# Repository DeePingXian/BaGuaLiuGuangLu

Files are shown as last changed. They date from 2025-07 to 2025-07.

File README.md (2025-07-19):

# 八卦流光爐☆
這是個主要當彩燈使用的開源八卦爐專案DA☆ZE  
<table>
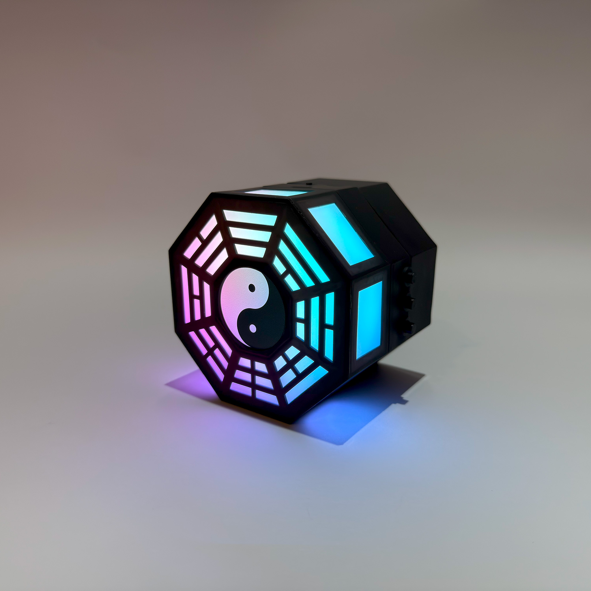
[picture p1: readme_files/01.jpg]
<tr><td align="center" colspan="2"><br></td></tr>
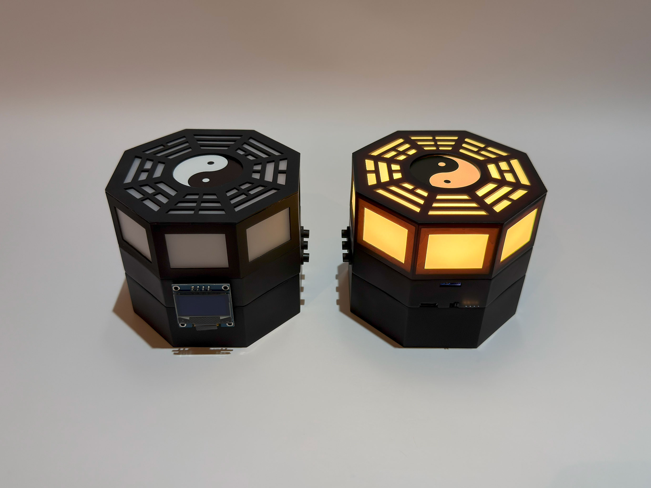
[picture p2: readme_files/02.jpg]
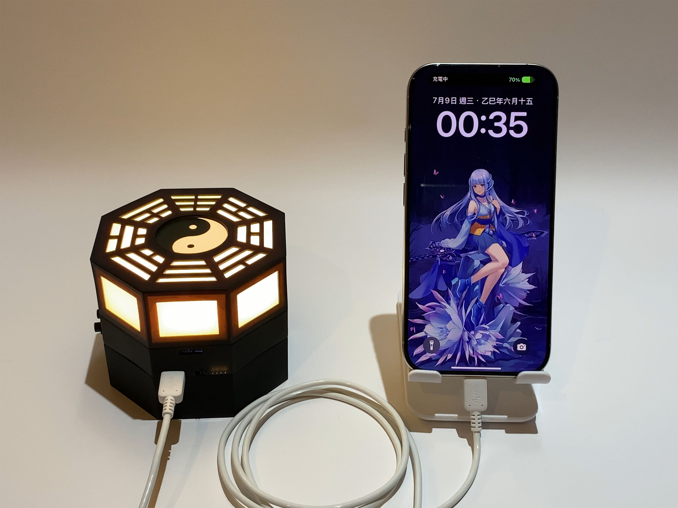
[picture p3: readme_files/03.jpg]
<tr><td align="center"><br></td><td align="center"><br></td></tr>
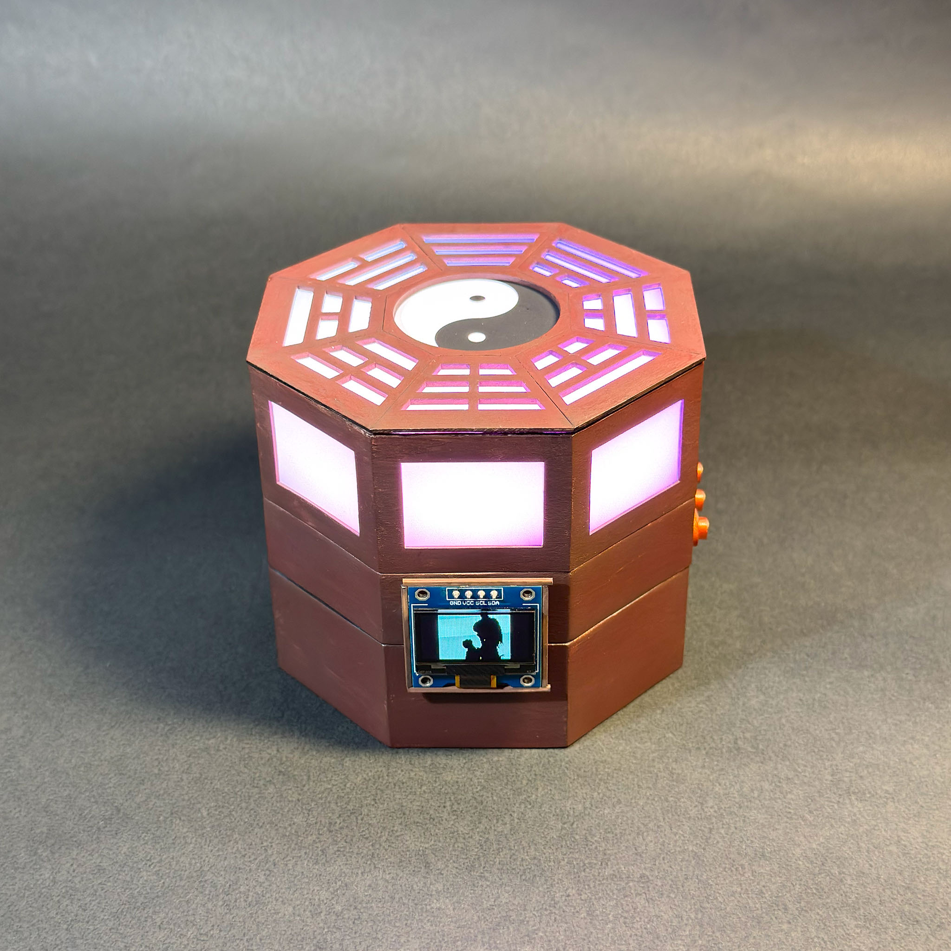
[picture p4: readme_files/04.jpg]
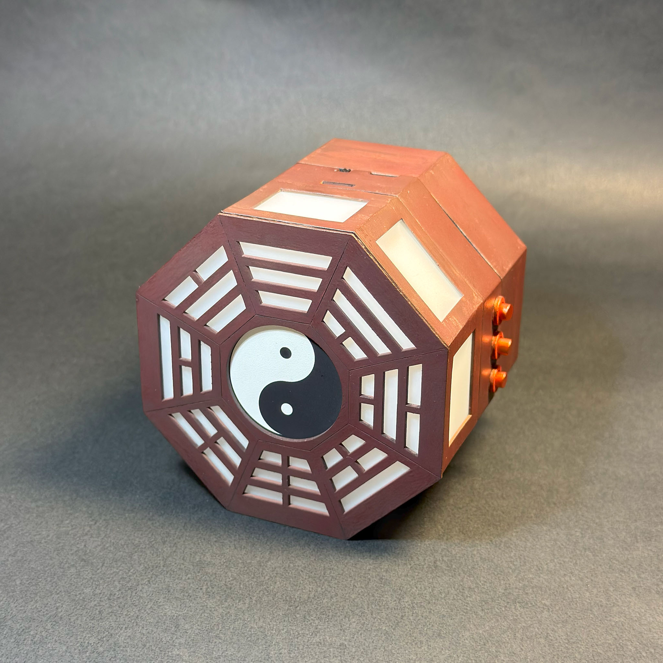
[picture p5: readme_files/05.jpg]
<tr><td align="center"><br></td><td align="center"><br></td></tr>
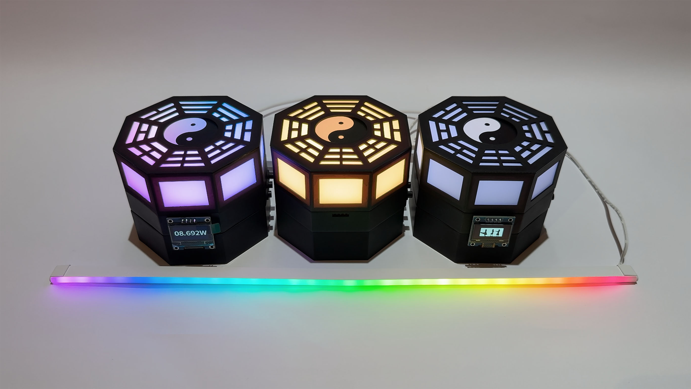
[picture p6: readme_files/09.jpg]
<tr><td align="center" colspan="2"><br></td></tr>
</table> 

## 功能介紹
- 自帶網頁+實體按鍵控制燈效
- 單USB-C孔之行動電源
- 顯示各項資訊的小螢幕
- 可外接電腦用之ARGB燈條
- 可選配藍牙喇叭模組
- OCP、OVP、OTP、ESD防護（未經任何標準檢驗）
- 有興趣也可自行修改成自己的版本
<br>

按鍵功能（按鍵面向自己時由左往右數）：  
- 按鍵1為燈控按鍵，短按一下調顏色、短按兩下調燈效模式、長按調燈光亮度
- 按鍵2為操控螢幕，短按切換畫面，長按開關螢幕
- 開機同時按住按鍵1、2一秒，可將整台裝置恢復預設值
- 按鍵3為行動電源按鍵，按一下開啟電源輸出，按兩下關閉輸出
<br>

螢幕顯示模式：  
- 充放電相關資訊、網路時鐘
- 充放電功率
- BadApple動畫
- 系統資訊

不安裝螢幕也可運作，請在關機狀態下插拔螢幕<br>
<br>
網頁控制功能，連線到此裝置的Wi-Fi後，在瀏覽器輸入小螢幕上的IP位址，即可進入控制頁面：<br>
預設SSID為「BaGuaLu」，密碼為「bagualu123」，IP為「192.168.4.1」<br>
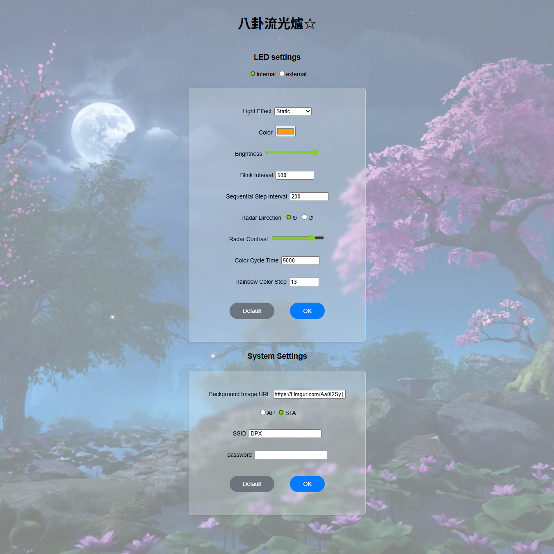
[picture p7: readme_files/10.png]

<br>
AP模式為裝置自成Wi-Fi基地台（預設值），STA則為連線至別的Wi-Fi<br>
設置完成後需要手動重新開機<br>
<br>
若設定連線到其他Wi-Fi，成功連上網際網路後，螢幕狀態顯示畫面最下面一欄會變為網路時鐘<br>
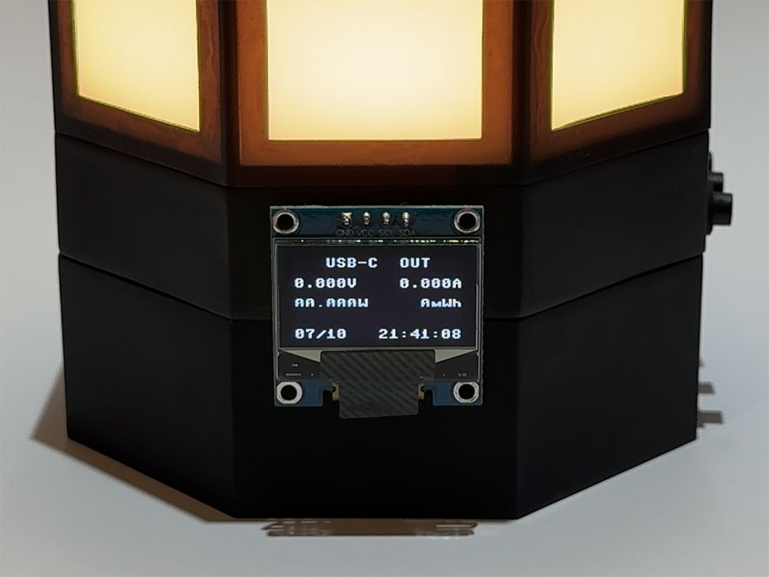
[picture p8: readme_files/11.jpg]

<br>
<br>

其餘事項
- 行動電源最高5V⎓3A輸出、2.4A輸入（實測2.6A），容量根據安裝的18650電池而定，若選擇製作教學中的型號，額定容量為6600mAh，實際容量會稍高一點
- 輸入電流大於4A時會啟動保護機制，無法充電，請排除狀況後重開機解除
- 當以接近最大功率充放電時，因過溫度保護機制設計的較敏感，會暫時降低功率，或直接關斷一段時間，直到溫度降低
- 裝置無法正常啟動、韌體更新完成時，請按照上方的方法重設裝置

## 展示短片
video (https://www.youtube.com/watch?v=Tj5yqzIPKYQ)

## 製作&組裝教學
本專案提供製作教學，若想瞭解技術細節，或實際上手製作，歡迎至<a href="https://github.com/DeePingXian/BaGuaLiuGuangLu/wiki">Wiki頁面</a>查看

## 製作人員
- 結構設計：<a href="https://thwiki.cc/%E6%B1%82%E9%97%BB%E5%B7%A5%E5%9D%8A">求聞工坊</a>
- 電路設計：<a href="https://www.facebook.com/DeePingXian">地平線 DeePingXian</a>
- 控制程式：<a href="https://www.facebook.com/DeePingXian">地平線 DeePingXian</a>
- 外殼模型：<a href="https://thwiki.cc/%E6%B1%82%E9%97%BB%E5%B7%A5%E5%9D%8A">求聞工坊</a>
- 外殼塗裝：<a href="https://www.facebook.com/j.kagamitsuki/posts/pfbid0qQWvzFg5CoFkT7tkbtXfqWopT1fieFPE1NWJFECgEJuv1Gb7SHNib1UmLF8mmVCvl">JKX鏡月</a>

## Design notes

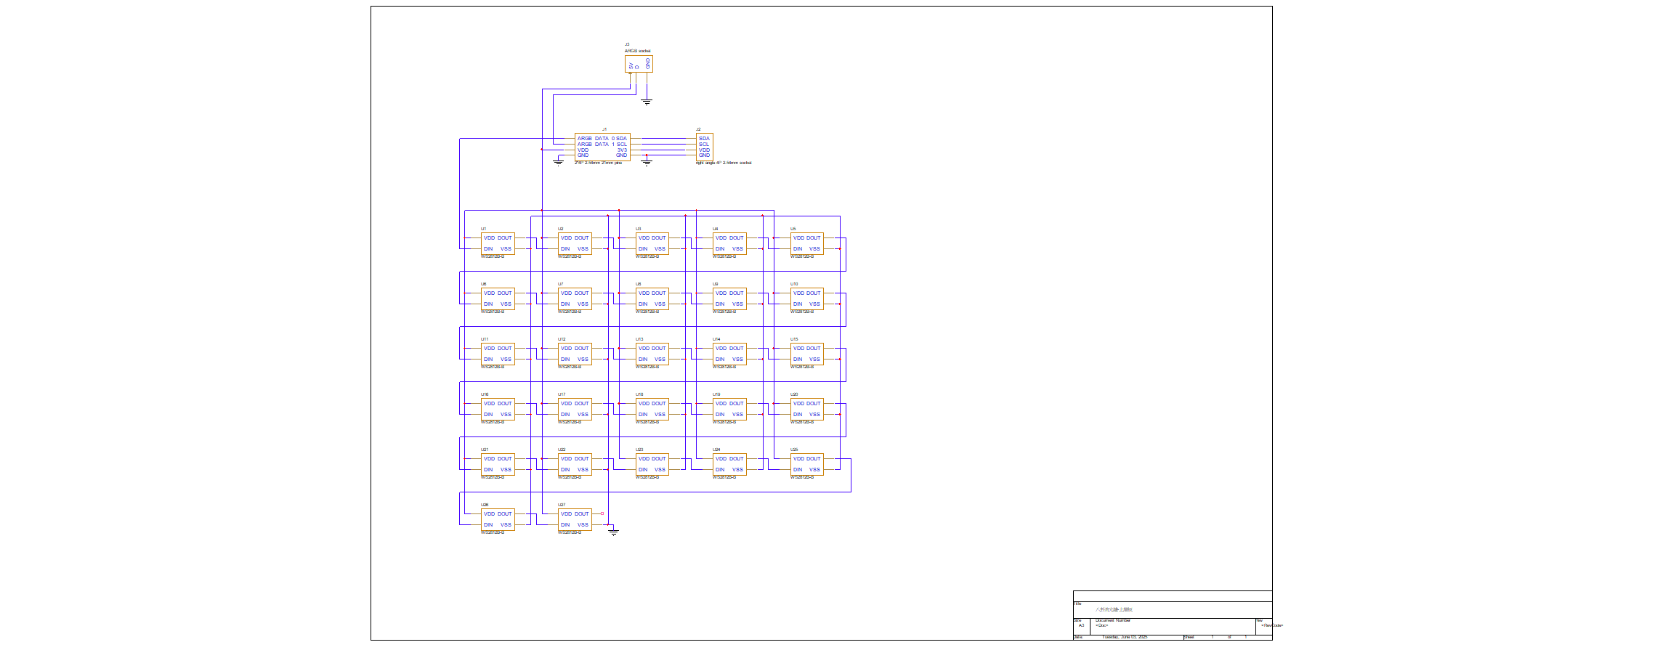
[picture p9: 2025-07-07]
circuit/upper_pcb/UPPER_PCB.png

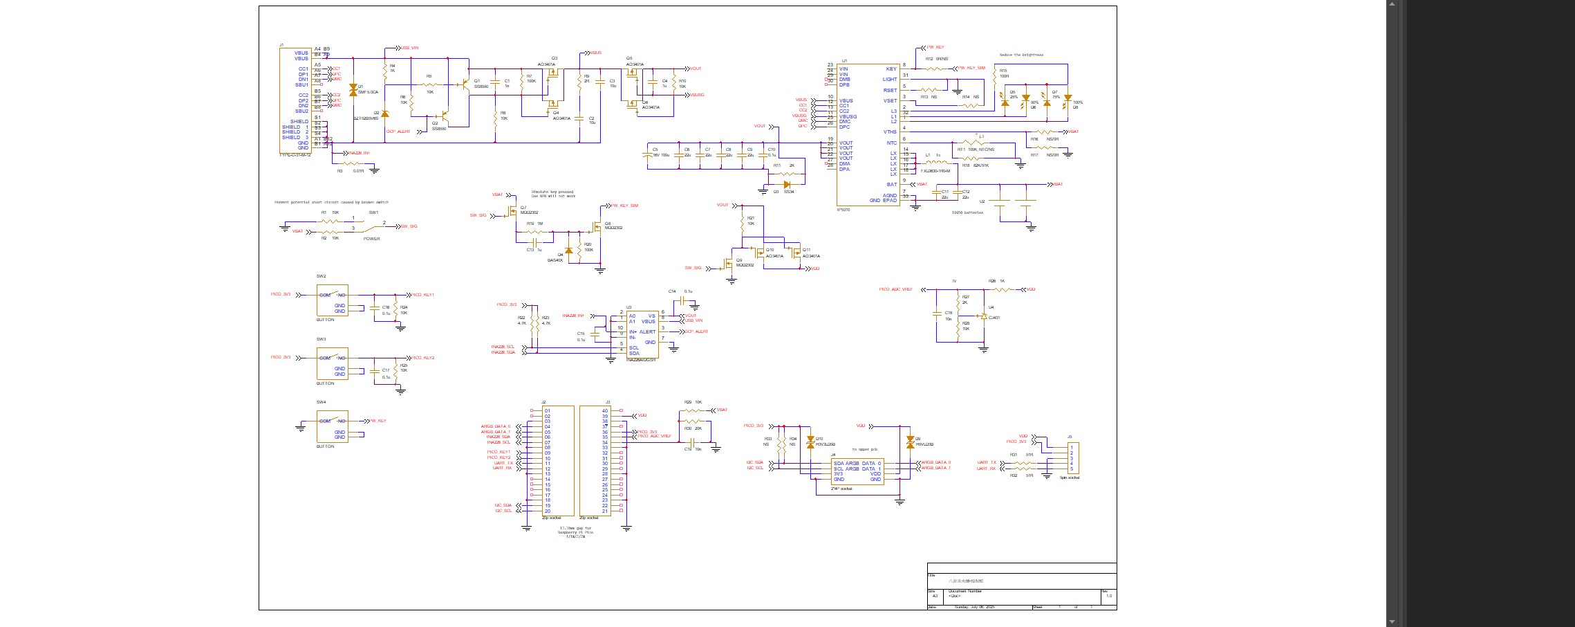
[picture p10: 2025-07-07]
circuit/control_pcb/CONTROL_CIRCUIT.png

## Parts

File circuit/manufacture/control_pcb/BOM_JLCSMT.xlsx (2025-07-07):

Comment | Designator | Footprint | JLCPCB Part #（optional）
10K R | R1,R2,R5,R6,R8,R10,R21,R24,R25,R28,R29 | 0603 | C25804
0.01 R | R3 | 1206 | C7467248
1K R | R4,R26 | 0603 | C21190
100K R | R7,R20 | 0603 | C25803
2 R | R9 | 0603 | C22977
2K R | R11,R27 | 0603 | C22975
0 R | R12 | 0603 | CC21189
100 R | R15 | 0603 | C22775
82K R | R18 | 0603 | C23254
4.7K R | R22,R23 | 0603 | C23162
1M R | R19 | 0603 | C22935
20K R | R30 | 0603 | C4184
51 R | R31,R32 | 0603 | C23197
100K_NTC | RT1 | 0603 | C919169
1n MLCC | C1 | 0603 | C1588
10u MLCC | C2,C3 | 0603 | C19702
1u MLCC | C4,C13 | 0603 | C15849
100u 16V Tantalum Capacitor | C5 | CASE-D-7343 | C129696
22u MLCC | C6,C7,C8,C9,C11,C12 | 0805 | C45783
0.1u MLCC | C10,C14,C15,C16,C17 | 0603 | C14663
10n MLCC | C18,C19 | 0603 | C57112
5V TVS | D1 | 1206 | C19077498
5.6V zener diode | D2 | SOD-323 | C19077435
schottky diode (SS34) | D3 | SMA | C8678
diode | D4 | SOD-523 | C22466370
LED | D5,D6,D7,D8 | 0603 | C2290
5V TVS | D9 | 0805 | C20615805
3.3V TVS | D10 | 0603 | C20615817
USB type-C connector | J1 | HRO_TYPE-C-31-M-12 | C165948
1*20P 2.54mm SMD socket | J2,J3 | SSM-120-L-SV-BE
2*4P 2.54mm socket | J4 | BCS-104-T-D-TE | C92271
1*5P 2.54mm socket | J5 | BCS-105-F-S-TE | C5116488
1uH inductor | L1 | INDM7066X300 | C167216
PNP_transistor | Q1,Q2 | SOT23-3 | C8542
N-MOSFET | Q7,Q8,Q9 | SOT23-3 | C427390
P-MOSFET | Q3,Q4,Q5,Q6,Q10,Q11 | SOT23-3 | C15127
right angle slide switch | SW1 | SW_EG1247 | C431547
right angle tactile switch | SW2,SW3,SW4 | SW_TS11-674-73-BK-160-RA-D | C2845271
IP5310 | U1 | QFN65P600X600X90-33N | C191176
18650 x2 battery case | U2 | 18650-PC4
INA226 | U3 | SOP50P490X110-10N | C49851
CJ431 | U4 | SOT23-3 | C3113

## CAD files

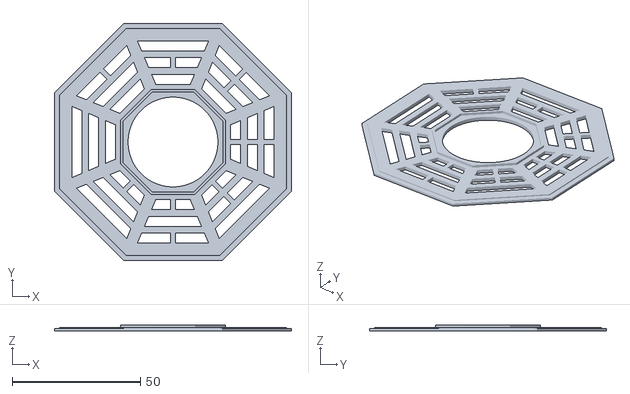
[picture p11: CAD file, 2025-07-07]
case/STL/top.stl
92.4 x 92.4 x 2.50

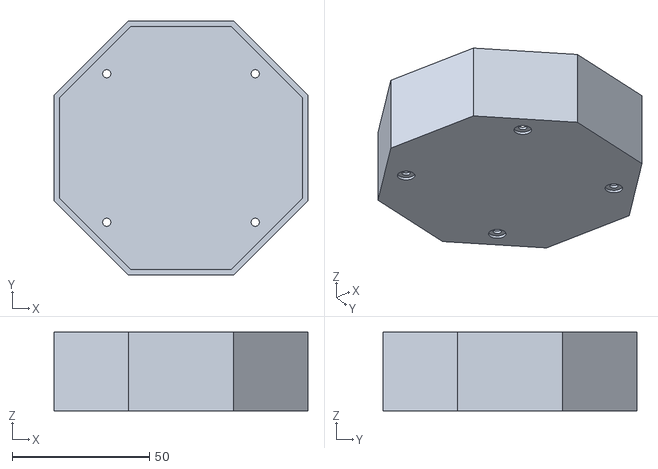
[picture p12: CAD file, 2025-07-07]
case/STL/lower.stl
92.4 x 92.4 x 28.6

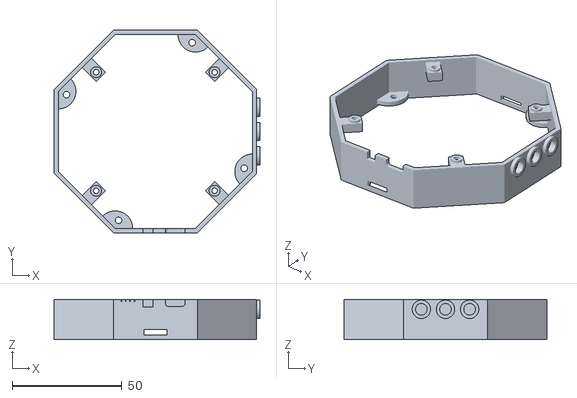
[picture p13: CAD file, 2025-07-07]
case/STL/mid.stl
93.9 x 92.4 x 18.3

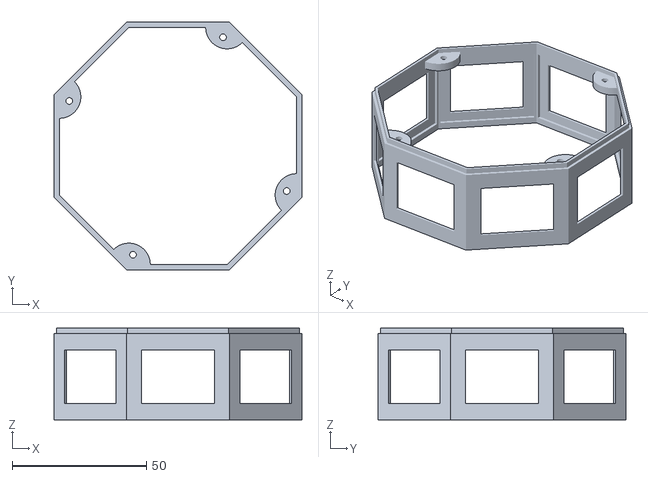
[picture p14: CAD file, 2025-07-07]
case/STL/upper.stl
92.4 x 92.4 x 34.1

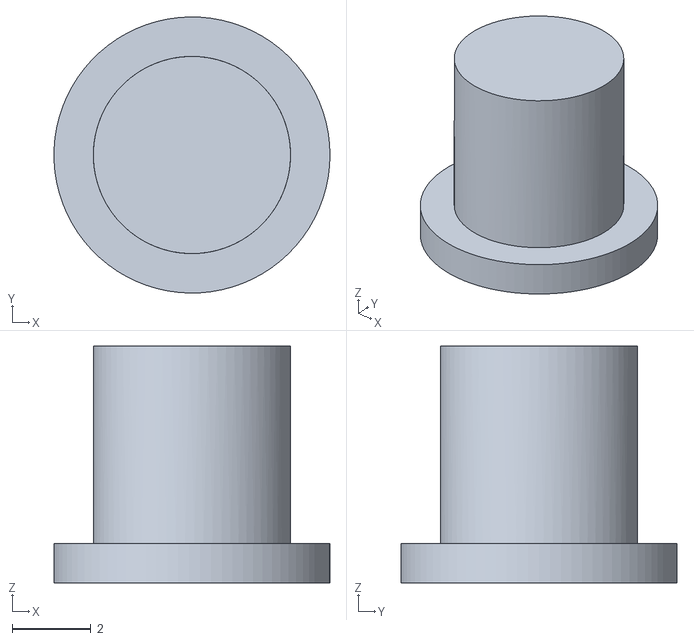
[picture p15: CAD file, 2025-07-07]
case/STL/btn.stl
7.00 x 7.00 x 6.00

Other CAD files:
case/LGP/顶面阴阳图均光板_面板打印_39x39x1mm.dwg

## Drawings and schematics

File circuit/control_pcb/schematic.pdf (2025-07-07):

Q1 SS8550 | C13 1u
L3 | 2 VSET | 3 VTHS | 4 RSET | 5 NTC | 6 AGND | 7

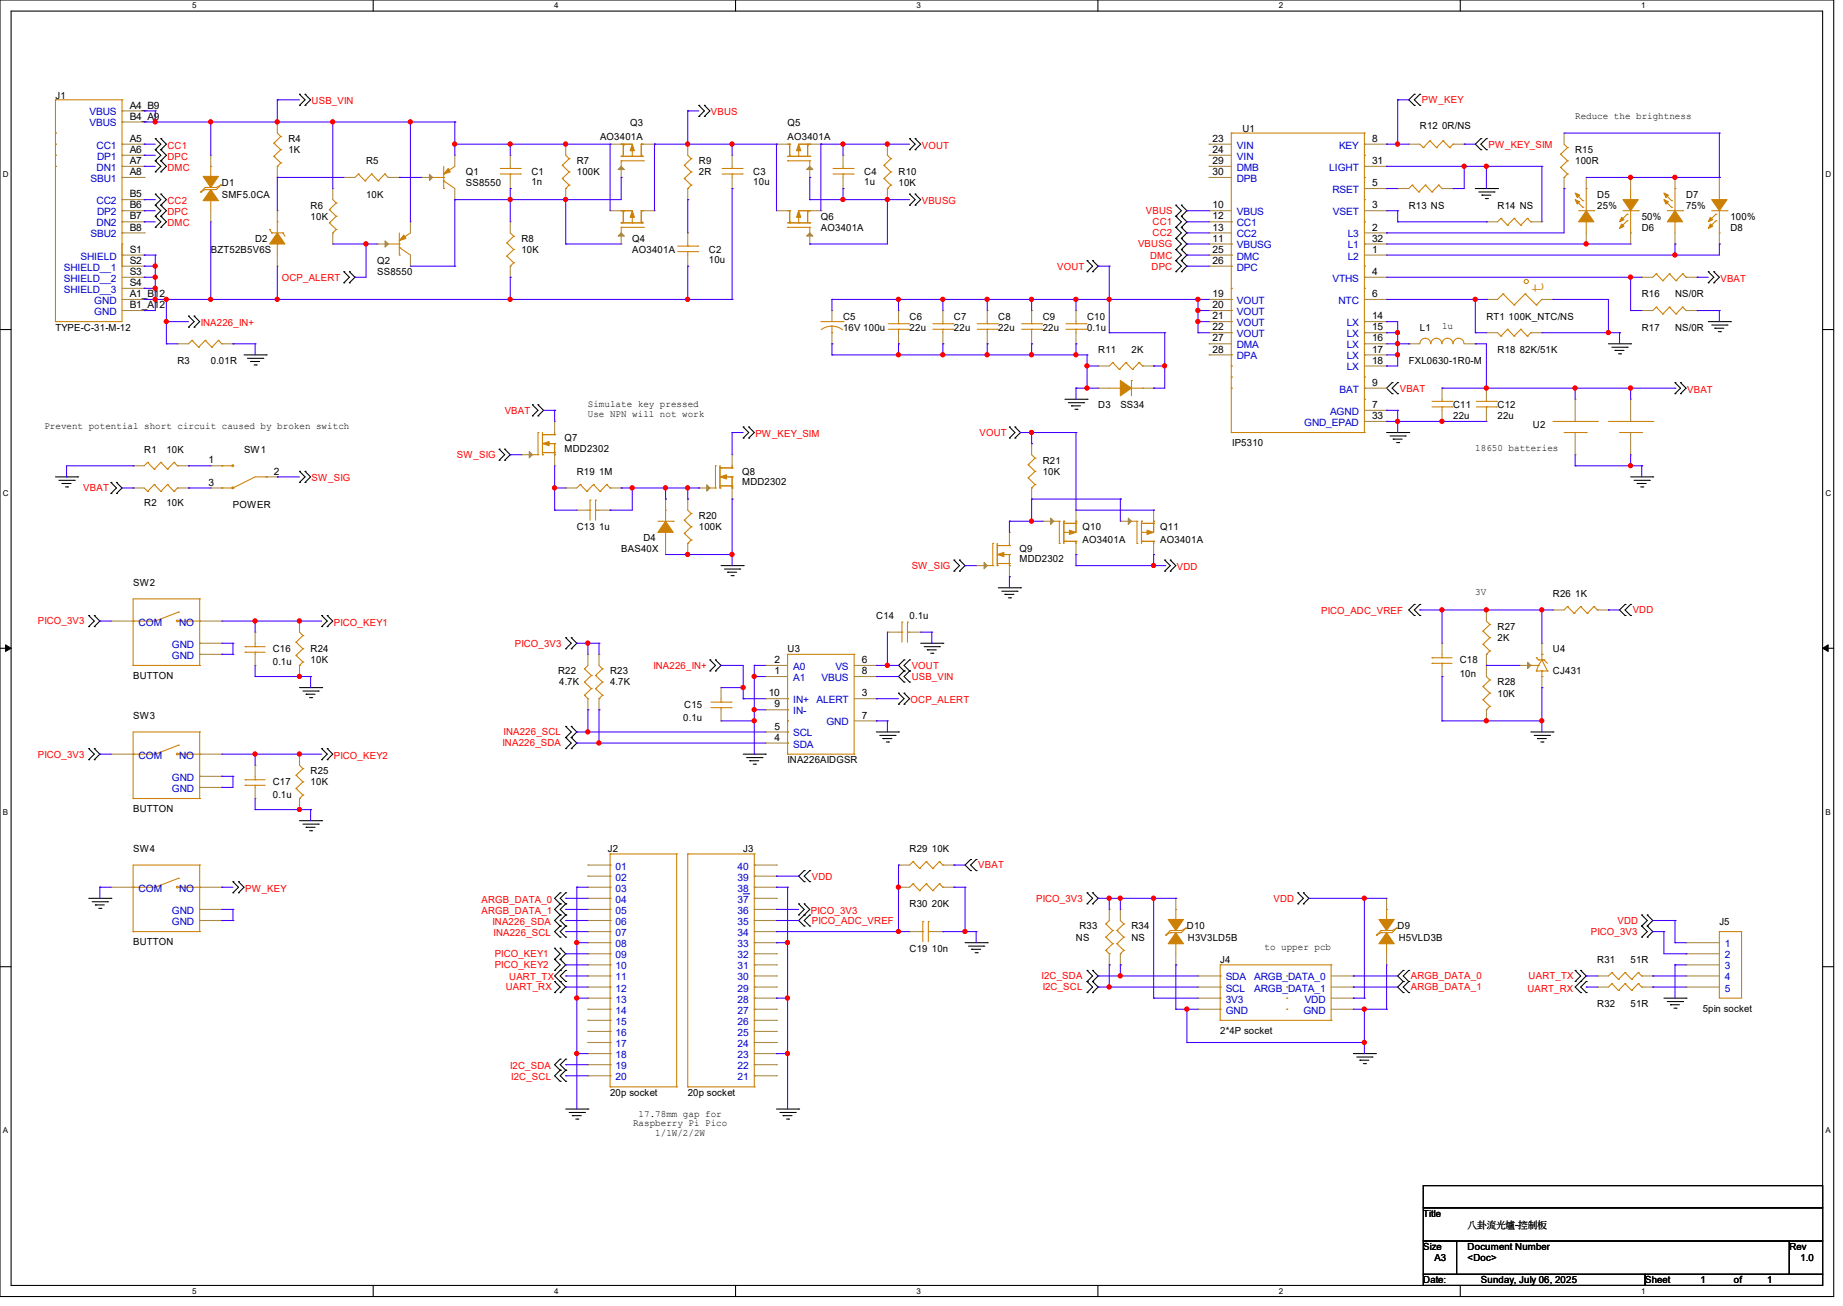
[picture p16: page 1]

Reduce the brightness VBUSG

Simulate key pressed
Use NPN will not work
Q7 MDD2302

Prevent potential short circuit caused by broken switch

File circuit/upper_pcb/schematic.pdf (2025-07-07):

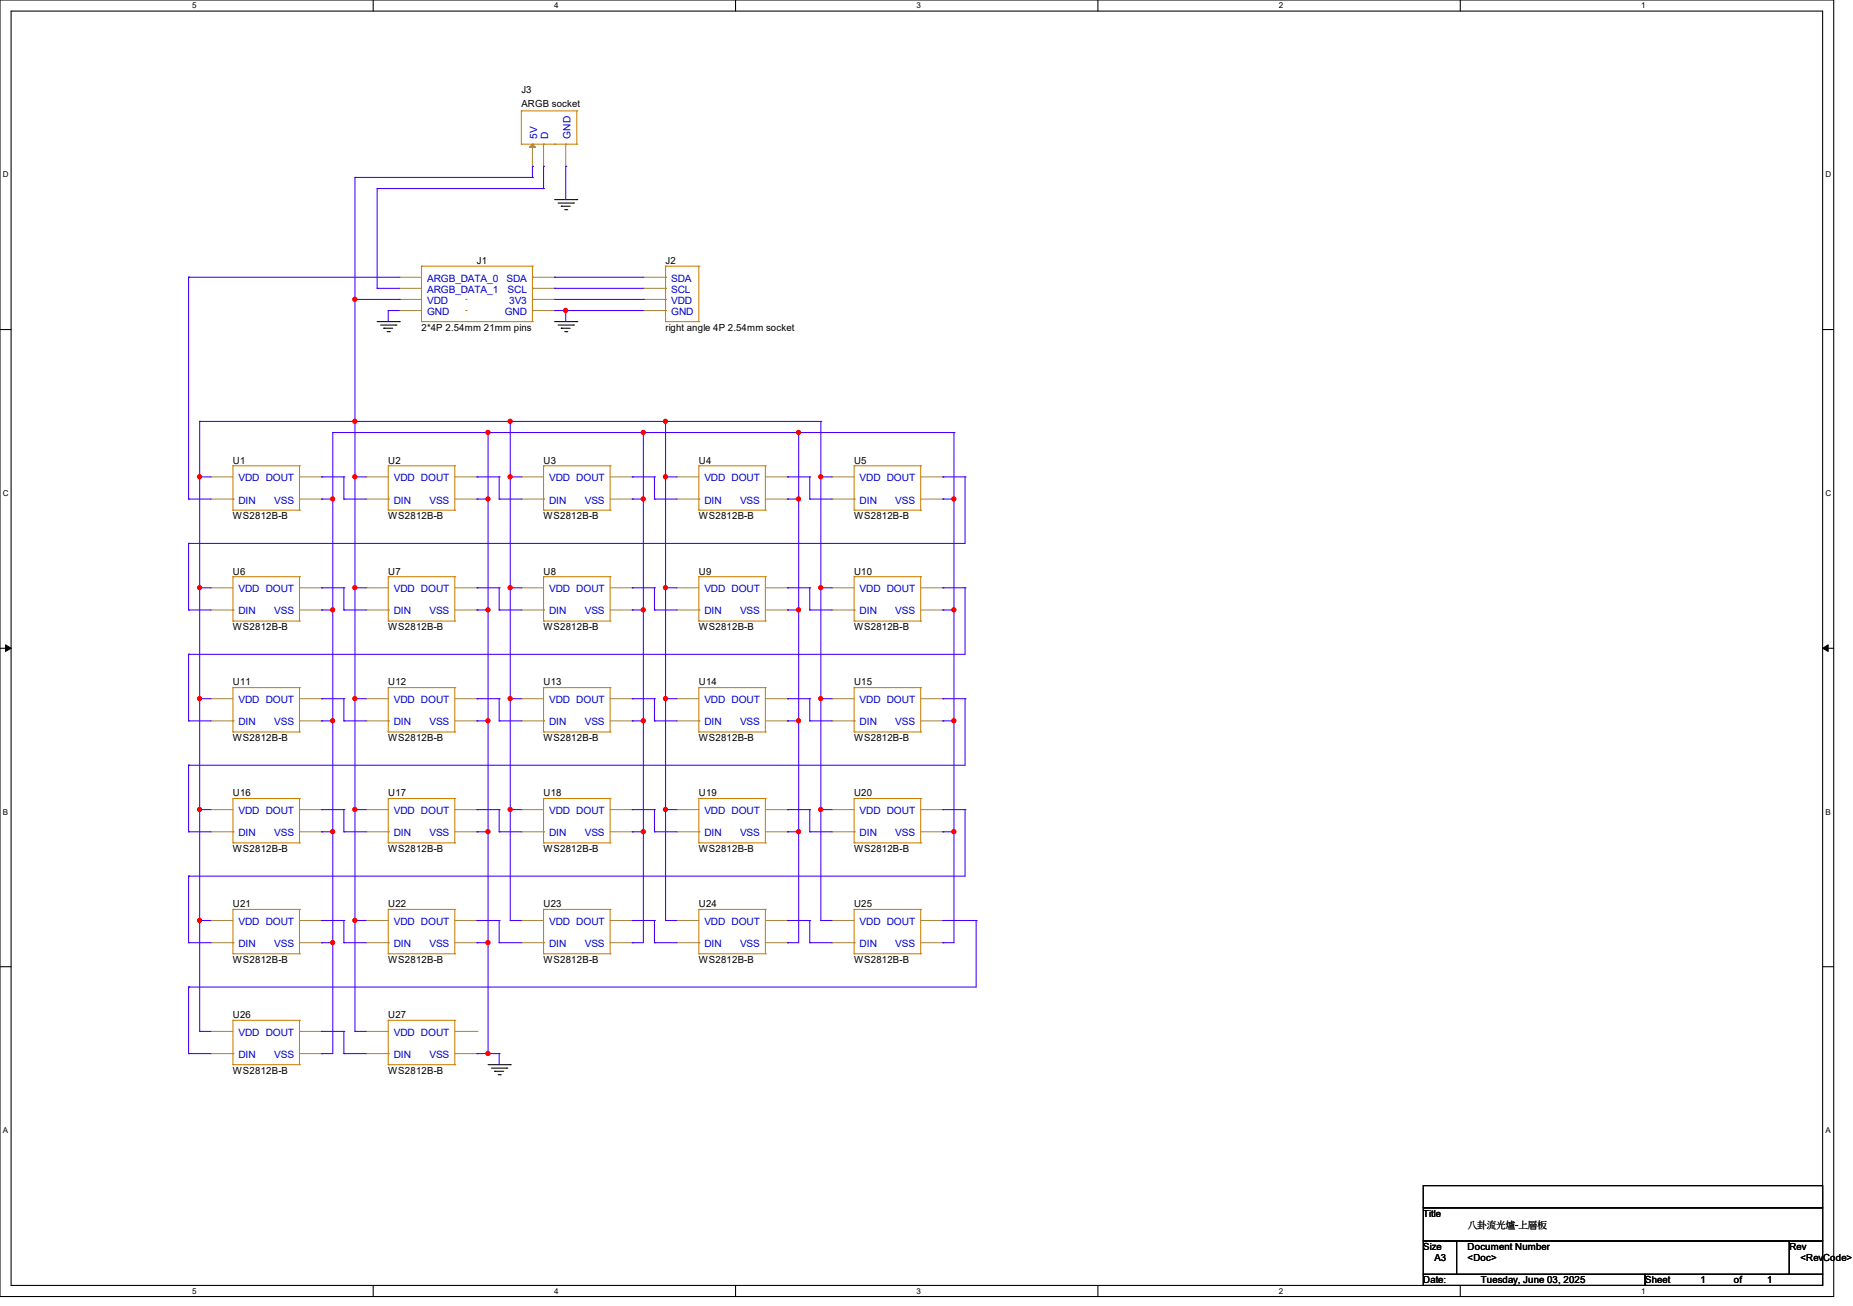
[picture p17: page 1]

right angle 4P 2.54mm socket SDA
SCL VDD GND

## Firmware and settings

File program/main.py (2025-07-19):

import machine, network, asyncio, gc, array, rp2, json, ubinascii, os, time, _thread, ina226, ssd1306, badapple, ntptime
from micropython import const

PROGRAM_VERSION = "25.07.07"
SUM_OF_INTERNAL_LEDS = const(27)
SHORT_PRESS_TIME = const(50)    #ms
LONG_PRESS_TIME = const(1000)
RELEASE_TIME = const(500)
SCREEN_REFRESH_INTERVAL = const(1000)
INA226_POSITIVE_CURRENT_COEFFICIENT = 0.999       #調整INA226誤差
INA226_NEGATIVE_CURRENT_COEFFICIENT = 0.9927
LOAD_INA226_INTERVAL = const(500)
ENABLE_INA226_OCP = const(1)
PICO_ADC_SINK_CURRENT = const(38)       #uA
NTP_SYNC_INTERVAL_HR = const(24)

ledButton = machine.Pin((6), machine.Pin.IN)
screenButton = machine.Pin((7), machine.Pin.IN)

settings = {}

def restore_default_settings(type=0):
    if type == 0:
        settings["wifi"] = {}
        settings["internalLed"] = {}
        settings["externalLed"] = {}
        settings["wifi"]["ssid"] = "BaGuaLu"
        settings["wifi"]["password"] = "bagualu123"
        settings["wifi"]["mode"] = 0
        settings["backgroundImageUrl"] = ""
        settings["internalLed"]["mode"] = 1     #0 關燈 1 單色開 2 單色閃 3 雷達 4 彩色循環 5 彩色流水
        settings["internalLed"]["color"] = [255, 160, 0]        #RGB format
        settings["internalLed"]["brightness"] = 100
        settings["internalLed"]["blinkInterval"] = 500
        settings["internalLed"]["sequentialStepInterval"] = 200
        settings["internalLed"]["sequentialDirection"] = True       #順時針亮起（否則逆時針）
        settings["internalLed"]["radarContrast"] = 80
        settings["internalLed"]["colorCycleTime"] = 5000
        settings["internalLed"]["rainbowColorStep"] = 13
        settings["externalLed"]["mode"] = 5     #0 關燈 1 單色開 2 單色閃 3 序列 4 彩色循環 5 彩色流水
        settings["externalLed"]["color"] = [255, 255, 255]
        settings["externalLed"]["brightness"] = 100
        settings["externalLed"]["blinkInterval"] = 500
        settings["externalLed"]["sequentialStepInterval"] = 200
        settings["externalLed"]["colorCycleTime"] = 5000
        settings["externalLed"]["rainbowColorStep"] = 10
        settings["externalLed"]["sumOfLeds"] = 30
    elif type == 1:
        settings["wifi"] = {}
        settings["internalLed"] = {}
        settings["externalLed"] = {}
        settings["wifi"]["ssid"] = "BaGuaLu"
        settings["wifi"]["password"] = "bagualu123"
        settings["wifi"]["mode"] = 0
        settings["backgroundImageUrl"] = ""
    elif type == 2:
        settings["internalLed"]["mode"] = 1
        settings["internalLed"]["color"] = [255, 160, 0]
        settings["internalLed"]["brightness"] = 100
        settings["internalLed"]["blinkInterval"] = 500
        settings["internalLed"]["sequentialStepInterval"] = 200
        settings["internalLed"]["sequentialDirection"] = True
        settings["internalLed"]["radarContrast"] = 80
        settings["internalLed"]["colorCycleTime"] = 5000
        settings["internalLed"]["rainbowColorStep"] = 13
    elif type == 3:
        settings["externalLed"]["mode"] = 5
        settings["externalLed"]["color"] = [255, 255, 255]
        settings["externalLed"]["brightness"] = 100
        settings["externalLed"]["blinkInterval"] = 500
        settings["externalLed"]["sequentialStepInterval"] = 200
        settings["externalLed"]["colorCycleTime"] = 5000
        settings["externalLed"]["rainbowColorStep"] = 10
        settings["externalLed"]["sumOfLeds"] = 30

    with open("./settings.json", "w", encoding="utf8") as f:
        json.dump(settings, f)

def load_settings():
    if not "settings.json" in os.listdir():
        restore_default_settings()
    global settings
    with open("./settings.json", "r", encoding="utf8") as f:
        settings = json.load(f)

def led_process():
    # https://github.com/raspberrypi/pico-micropython-examples/blob/master/pio/neopixel_ring/neopixel_ring.py
    # Raspberry Pi Pico 的PIO 程式，用於控制 WS2812B LED
    @rp2.asm_pio(sideset_init=rp2.PIO.OUT_LOW, out_shiftdir=rp2.PIO.SHIFT_LEFT, autopull=True, pull_thresh=24)
    def ws2812():
        T1 = 2
        T2 = 5
        T3 = 3
        wrap_target()
        label("bitloop")
        out(x, 1)               .side(0)    [T3 - 1]
        jmp(not_x, "do_zero")   .side(1)    [T1 - 1]
        jmp("bitloop")          .side(1)    [T2 - 1]
        label("do_zero")
        nop()                   .side(0)    [T2 - 1]
        wrap()

    class NeoPixel:
        def __init__(self, pin, ledSum, pioId, bpp=3, timing=1):
            self.ledSum = ledSum
            self.bpp = bpp
            self.pin = pin
            self.buf = array.array("I", [0] * ledSum)
            self.sm = rp2.StateMachine(pioId, ws2812, freq=8000000, sideset_base=pin)
            self.sm.active(1)

        def __len__(self):
            return self.ledSum

        def __getitem__(self, index):
            return ((self.buf[index]>>16)&0xFF, (self.buf[index]>>8)&0xFF, self.buf[index]&0xFF)

        def __setitem__(self, index, val):
            self.buf[index] = val[0]<<16 | val[1]<<8 | val[2]

        def write(self):
            # 將 RGB 資料轉換為 GRB，符合 WS2812B 的資料格式
            grb = array.array("I", [0] * self.ledSum)
            for i in range(self.ledSum):
                r = (self.buf[i]>>16) & 0xFF
                g = (self.buf[i]>>8) & 0xFF
                b = self.buf[i] & 0xFF
                grb[i] = (g<<16) | (r<<8) | b
            self.sm.put(grb, 8)

    def RGBtoHSV(colorInput):
        r = colorInput[0] / 255
        g = colorInput[1] / 255
        b = colorInput[2] / 255
        c_max = max(r, g, b)
        c_min = min(r, g, b)
        delta = c_max - c_min
        if delta == 0:
            h = 0
        elif c_max == r:
            h = (60 * ((g - b) / delta) + 360) % 360
        elif c_max == g:
            h = (60 * ((b - r) / delta) + 120) % 360
        else:
            h = (60 * ((r - g) / delta) + 240) % 360
        s = 0 if c_max == 0 else delta / c_max
        v = c_max
        return (int(round(h, 0)), int(round(s * 100, 0)), int(round(v*100, 0)))

    def HSVtoRGB(colorInput):
        #https://zh.m.wikipedia.org/zh-tw/HSL%E5%92%8CHSV%E8%89%B2%E5%BD%A9%E7%A9%BA%E9%97%B4
        color = [colorInput[0], colorInput[1], colorInput[2]]
        color[1] /= 100
        color[2] /= 100
        hi = color[0] // 60
        f = color[0] / 60 - hi
        p = color[2] * (1 - color[1])
        q = color[2] * (1 - f * color[1])
        t = color[2] * (1 - (1 - f) * color[1])
        if hi == 0:
            return (int(round(color[2] * 255, 0)), int(round(t * 255, 0)), int(round(p * 255, 0)))
        elif hi == 1:
            return (int(round(q * 255, 0)), int(round(color[2] * 255, 0)), int(round(p * 255, 0)))
        elif hi == 2:
            return (int(round(p * 255, 0)), int(round(color[2] * 255, 0)), int(round(t * 255, 0)))
        elif hi == 3:
            return (int(round(p * 255, 0)), int(round(q * 255, 0)), int(round(color[2] * 255, 0)))
        elif hi == 4:
            return (int(round(t * 255, 0)), int(round(p * 255, 0)), int(round(color[2] * 255, 0)))
        elif hi == 5:
            return (int(round(color[2] * 255, 0)), int(round(p * 255, 0)), int(round(q * 255, 0)))

    internalLed = NeoPixel(machine.Pin(2), SUM_OF_INTERNAL_LEDS, 0)
    externalLed = NeoPixel(machine.Pin(3), settings["externalLed"]["sumOfLeds"], 1)
        
    def setLed(ledType, ledcolor, startNum=0, endNum=SUM_OF_INTERNAL_LEDS, scaleWithBrightness=False):
        if ledType == 1:        #0 internal 1 external
            endNum = settings["externalLed"]["sumOfLeds"]
        color = [ledcolor[0], ledcolor[1], ledcolor[2]]
        if scaleWithBrightness:
            if ledType == 0:
                for i in range(3):
                    color[i] = int(color[i]*settings["internalLed"]["brightness"]/100)
            else:
                for i in range(3):
                    color[i] = int(color[i]*settings["externalLed"]["brightness"]/100)
        if ledType == 0:
            for i in range(startNum, endNum, 1):
                internalLed[i] = tuple(color)
            internalLed.write()
        else:
            for i in range(startNum, endNum, 1):
                externalLed[i] = tuple(color)
            externalLed.write()

    setLed(0, (0, 0, 0))
    setLed(1, (0, 0, 0))

    lastLedButtonState, lastLedButtonPressedTime, lastLedButtonLongPressedTime, lastLedButtonReleasedTime, ledButtonShortPressedTimes = 0, time.ticks_ms(), time.ticks_ms(), time.ticks_ms(), 0
    lastInternalLedMode, lastInternalLedColor, lastInternalLedBrightness = 0, (), 0
    lastExternalLedMode, lastExternalLedColor, lastExternalLedBrightness, lastExternalLedSum = 0, (), 0, settings["externalLed"]["sumOfLeds"]
    internalLedMode3TargetLed = ((3, 4), (6, 7), (9, 10), (12, 13), (15, 16), (18, 19), (21, 22), (24, 25))
    internalLedMode2Param = [0, 0]
    internalLedMode3Param = [0, 0]     #八卦方位 上次動作時間
    internalLedMode4Param = [0, 0]    #H座標, 上次動作時間
    internalLedMode5Param = [0, 0]    #第一顆燈之H座標, 上次動作時間
    externalLedMode2Param = [0, 0]
    externalLedMode3Param = [0, 0, True]     #燈編號, 上次動作時間, 順向亮起（某則逆向）
    externalLedMode4Param = [0, 0]    #H座標, 上次動作時間
    externalLedMode5Param = [0, 0]    #第一顆燈之H座標, 上次動作時間

    def setLastLedColor(ledType):
        if ledType == 0:
            nonlocal lastInternalLedColor, lastInternalLedBrightness
            lastInternalLedColor, lastInternalLedBrightness = settings["internalLed"]["color"], settings["internalLed"]["brightness"]
        else:
            nonlocal lastExternalLedColor, lastExternalLedBrightness
            lastExternalLedColor, lastExternalLedBrightness = settings["externalLed"]["color"], settings["externalLed"]["brightness"]

    def isColorChanged(ledType):
        if ledType == 0:
            return True if settings["internalLed"]["color"] != lastInternalLedColor or settings["internalLed"]["brightness"] != lastInternalLedBrightness else False
        else:
            return True if settings["externalLed"]["color"] != lastExternalLedColor or settings["externalLed"]["brightness"] != lastExternalLedBrightness else False

    while True:
        #調整設定
        settingsChanged = False
        #偵測按鈕狀態
        if lastLedButtonState == 0 and ledButton.value() == 1:
            lastLedButtonPressedTime = time.ticks_ms()
            lastLedButtonState = 1
        if lastLedButtonState == 1 and ledButton.value() == 0 and (time.ticks_diff(time.ticks_ms(), lastLedButtonPressedTime) >= SHORT_PRESS_TIME and time.ticks_diff(time.ticks_ms(), lastLedButtonPressedTime) < LONG_PRESS_TIME and time.ticks_diff(time.ticks_ms(), lastLedButtonLongPressedTime) >= LONG_PRESS_TIME):    #短按
            lastLedButtonState = 0
            lastLedButtonReleasedTime = time.ticks_ms()
            ledButtonShortPressedTimes += 1
        if lastLedButtonState == 1 and ledButton.value() == 0 and (time.ticks_diff(time.ticks_ms(), lastLedButtonPressedTime) < SHORT_PRESS_TIME or time.ticks_diff(time.ticks_ms(), lastLedButtonPressedTime) >= LONG_PRESS_TIME or time.ticks_diff(time.ticks_ms(), lastLedButtonLongPressedTime) < LONG_PRESS_TIME):    #無效放開
            lastLedButtonState = 0
            lastLedButtonReleasedTime = time.ticks_ms()
        if ledButton.value() == 0 and time.ticks_diff(time.ticks_ms(), lastLedButtonReleasedTime) >= RELEASE_TIME and ledButtonShortPressedTimes > 0:  #短按結束
            if ledButtonShortPressedTimes == 1 and (settings["internalLed"]["mode"] in (1, 2, 3)):    #短按一下變色
                ledHsvColor = list(RGBtoHSV(settings["internalLed"]["color"]))
                if ledHsvColor[0] == 0 and ledHsvColor[1] == 0:      #白
                    ledHsvColor[1] = 100     #紅
                else:
                    ledHsvColor[0] = ((ledHsvColor[0] // 30 + 1) * 30) % 360
                    ledHsvColor[1] = 100 if ledHsvColor[0] != 0 else 0
                settings["internalLed"]["color"] = HSVtoRGB(ledHsvColor)
            elif ledButtonShortPressedTimes == 2:    #短按兩下調模式
                settings["internalLed"]["mode"] = settings["internalLed"]["mode"] + 1 if settings["internalLed"]["mode"] <= 4 else 0
            ledButtonShortPressedTimes = 0
            settingsChanged = True
        if lastLedButtonState == 1 and time.ticks_diff(time.ticks_ms(), lastLedButtonPressedTime) >= LONG_PRESS_TIME:      #長按調亮度
            lastLedButtonPressedTime, lastLedButtonLongPressedTime = time.ticks_ms(), time.ticks_ms()
            settings["internalLed"]["brightness"] = settings["internalLed"]["brightness"] - 20 if settings["internalLed"]["brightness"] > 20 else 100
            settingsChanged = True
        if settingsChanged:
            with open("./settings.json", "w", encoding="utf8") as f:
                json.dump(settings, f)
        
        #調整內部燈光
        if settings["internalLed"]["mode"] == 0 and lastInternalLedMode != 0:
            lastInternalLedMode = 0
            setLed(0, (0, 0, 0))
        elif settings["internalLed"]["mode"] == 1:
            if lastInternalLedMode != 1:
                lastInternalLedMode = 1
                setLastLedColor(0)
                setLed(0, settings["internalLed"]["color"], scaleWithBrightness=True)
            elif isColorChanged(0):
                setLastLedColor(0)
                setLed(0, settings["internalLed"]["color"], scaleWithBrightness=True)
        elif settings["internalLed"]["mode"] == 2:
            if lastInternalLedMode != 2:
                lastInternalLedMode = 2
                setLastLedColor(0)
                internalLedMode2Param = [time.ticks_ms(), time.ticks_ms()]
                setLed(0, settings["internalLed"]["color"], scaleWithBrightness=True)
            elif isColorChanged(0):
                setLastLedColor(0)
                if time.ticks_diff(time.ticks_ms(), internalLedMode2Param[0]) < settings["internalLed"]["blinkInterval"]:
                    setLed(0, settings["internalLed"]["color"], scaleWithBrightness=True)
            if lastInternalLedMode == 2 and time.ticks_diff(time.ticks_ms(), internalLedMode2Param[0]) >= settings["internalLed"]["blinkInterval"]:
                if time.ticks_diff(time.ticks_ms(), internalLedMode2Param[1]) < settings["internalLed"]["blinkInterval"] * 2:
                    setLed(0, (0, 0, 0))
                else:
                    internalLedMode2Param = [time.ticks_ms(), time.ticks_ms()]
                    setLed(0, settings["internalLed"]["color"], scaleWithBrightness=True)
        elif settings["internalLed"]["mode"] == 3:
            if lastInternalLedMode != 3:
                lastInternalLedMode = 3
                setLastLedColor(0)
                for i in (0, 1, 2):
                    internalLed[i] = (int(settings["internalLed"]["color"][0]*settings["internalLed"]["brightness"]/100*((100-settings["internalLed"]["radarContrast"])/100)), int(settings["internalLed"]["color"][1]*settings["internalLed"]["brightness"]/100*((100-settings["internalLed"]["radarContrast"])/100)), int(settings["internalLed"]["color"][2]*settings["internalLed"]["brightness"]/100*((100-settings["internalLed"]["radarContrast"])/100)))
                for i in (3, 4):
                    internalLed[i] = (int(settings["internalLed"]["color"][0]*settings["internalLed"]["brightness"]/100), int(settings["internalLed"]["color"][1]*settings["internalLed"]["brightness"]/100), int(settings["internalLed"]["color"][2]*settings["internalLed"]["brightness"]/100))
                for i in range(5, SUM_OF_INTERNAL_LEDS, 1):
                    internalLed[i] = (0, 0, 0)
                internalLedMode3Param[0], internalLedMode3Param[1] = 0, time.ticks_ms()
                internalLed.write()
            elif isColorChanged(0):
                setLastLedColor(0)
                for i in (0, 1, 2):
                    internalLed[i] = (int(settings["internalLed"]["color"][0]*settings["internalLed"]["brightness"]/100*((100-settings["internalLed"]["radarContrast"])/100)), int(settings["internalLed"]["color"][1]*settings["internalLed"]["brightness"]/100*((100-settings["internalLed"]["radarContrast"])/100)), int(settings["internalLed"]["color"][2]*settings["internalLed"]["brightness"]/100*((100-settings["internalLed"]["radarContrast"])/100)))             
                for i in internalLedMode3TargetLed[internalLedMode3Param[0]]:
                    internalLed[i] = (int(settings["internalLed"]["color"][0]*settings["internalLed"]["brightness"]/100), int(settings["internalLed"]["color"][1]*settings["internalLed"]["brightness"]/100), int(settings["internalLed"]["color"][2]*settings["internalLed"]["brightness"]/100))
                internalLed.write()
            if lastInternalLedMode == 3 and time.ticks_diff(time.ticks_ms(), internalLedMode3Param[1]) >= settings["internalLed"]["sequentialStepInterval"]:
                if settings["internalLed"]["sequentialDirection"]:
                    internalLedMode3Param[0] += 1
                    if internalLedMode3Param[0] >= 8:
                        internalLedMode3Param[0] = 0
                else:
                    internalLedMode3Param[0] -= 1
                    if internalLedMode3Param[0] < 0:
                        internalLedMode3Param[0] = 7
                for i in (0, 1, 2):
                    internalLed[i] = (int(settings["internalLed"]["color"][0]*settings["internalLed"]["brightness"]/100*((100-settings["internalLed"]["radarContrast"])/100)), int(settings["internalLed"]["color"][1]*settings["internalLed"]["brightness"]/100*((100-settings["internalLed"]["radarContrast"])/100)), int(settings["internalLed"]["color"][2]*settings["internalLed"]["brightness"]/100*((100-settings["internalLed"]["radarContrast"])/100)))
                for i in range(3, SUM_OF_INTERNAL_LEDS, 1):
                    if i in internalLedMode3TargetLed[internalLedMode3Param[0]]:
                        internalLed[i] = (int(settings["internalLed"]["color"][0]*settings["internalLed"]["brightness"]/100), int(settings["internalLed"]["color"][1]*settings["internalLed"]["brightness"]/100), int(settings["internalLed"]["color"][2]*settings["internalLed"]["brightness"]/100))
                    else:
                        internalLed[i] = (0, 0, 0)
                internalLedMode3Param[1] = time.ticks_ms()
                internalLed.write()
        elif settings["internalLed"]["mode"] == 4:
            setLastLedColor(0)
            if lastInternalLedMode != 4:
                lastInternalLedMode = 4
                internalLedMode4Param = [0, time.ticks_ms()]
                setLed(0, HSVtoRGB((internalLedMode4Param[0], 100, settings["internalLed"]["brightness"])))
            elif time.ticks_diff(time.ticks_ms(), internalLedMode4Param[1]) >= settings["internalLed"]["colorCycleTime"] / 360:
                internalLedMode4Param[0] += int(round(time.ticks_diff(time.ticks_ms(), internalLedMode4Param[1]) / (settings["internalLed"]["colorCycleTime"]/360), 0))
                if internalLedMode4Param[0] >= 360:
                    internalLedMode4Param[0] = 0
                internalLedMode4Param[1] = time.ticks_ms()
                setLed(0, HSVtoRGB((internalLedMode4Param[0], 100, settings["internalLed"]["brightness"])))
        elif settings["internalLed"]["mode"] == 5:
            setLastLedColor(0)
            if lastInternalLedMode != 5:
                lastInternalLedMode = 5
                for i in range(SUM_OF_INTERNAL_LEDS):
                    h = internalLedMode5Param[0] + i*settings["internalLed"]["rainbowColorStep"]
                    h = h if h < 360 else h % 360
                    internalLed[i] = HSVtoRGB((h, 100, settings["internalLed"]["brightness"]))
                internalLedMode5Param[0], internalLedMode5Param[1] = 0, time.ticks_ms()
                internalLed.write()
            elif time.ticks_diff(time.ticks_ms(), internalLedMode5Param[1]) >= settings["internalLed"]["colorCycleTime"] / 360:
                internalLedMode5Param[0] += int(round(time.ticks_diff(time.ticks_ms(), internalLedMode5Param[1]) / (settings["internalLed"]["colorCycleTime"]/360), 0))
                if internalLedMode5Param[0] >= 360:
                    internalLedMode5Param[0] = 0
                for i in range(SUM_OF_INTERNAL_LEDS):
                    h = internalLedMode5Param[0] + i*settings["internalLed"]["rainbowColorStep"]
                    h = h if h < 360 else h % 360
                    internalLed[i] = HSVtoRGB((h, 100, settings["internalLed"]["brightness"]))
                internalLedMode5Param[1] = time.ticks_ms()
                internalLed.write()
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

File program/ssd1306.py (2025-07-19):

#MIT License
#
#Copyright (c) 2018 Stefan Lehmann
#
#Permission is hereby granted, free of charge, to any person obtaining a copy
#of this software and associated documentation files (the "Software"), to deal
#in the Software without restriction, including without limitation the rights
#to use, copy, modify, merge, publish, distribute, sublicense, and/or sell
#copies of the Software, and to permit persons to whom the Software is
#furnished to do so, subject to the following conditions:
#
#The above copyright notice and this permission notice shall be included in all
#copies or substantial portions of the Software.
#
#THE SOFTWARE IS PROVIDED "AS IS", WITHOUT WARRANTY OF ANY KIND, EXPRESS OR
#IMPLIED, INCLUDING BUT NOT LIMITED TO THE WARRANTIES OF MERCHANTABILITY,
#FITNESS FOR A PARTICULAR PURPOSE AND NONINFRINGEMENT. IN NO EVENT SHALL THE
#AUTHORS OR COPYRIGHT HOLDERS BE LIABLE FOR ANY CLAIM, DAMAGES OR OTHER
#LIABILITY, WHETHER IN AN ACTION OF CONTRACT, TORT OR OTHERWISE, ARISING FROM,
#OUT OF OR IN CONNECTION WITH THE SOFTWARE OR THE USE OR OTHER DEALINGS IN THE
#SOFTWARE.

# MicroPython SSD1306 OLED driver, I2C and SPI interfaces

from micropython import const
import framebuf


# register definitions
SET_CONTRAST = const(0x81)
SET_ENTIRE_ON = const(0xA4)
SET_NORM_INV = const(0xA6)
SET_DISP = const(0xAE)
SET_MEM_ADDR = const(0x20)
SET_COL_ADDR = const(0x21)
SET_PAGE_ADDR = const(0x22)
SET_DISP_START_LINE = const(0x40)
SET_SEG_REMAP = const(0xA0)
SET_MUX_RATIO = const(0xA8)
SET_COM_OUT_DIR = const(0xC0)
SET_DISP_OFFSET = const(0xD3)
SET_COM_PIN_CFG = const(0xDA)
SET_DISP_CLK_DIV = const(0xD5)
SET_PRECHARGE = const(0xD9)
SET_VCOM_DESEL = const(0xDB)
SET_CHARGE_PUMP = const(0x8D)

# Subclassing FrameBuffer provides support for graphics primitives
# http://docs.micropython.org/en/latest/pyboard/library/framebuf.html
class SSD1306(framebuf.FrameBuffer):
    def __init__(self, width, height, external_vcc):
        self.width = width
        self.height = height
        self.external_vcc = external_vcc
        self.pages = self.height // 8
        self.buffer = bytearray(self.pages * self.width)
        super().__init__(self.buffer, self.width, self.height, framebuf.MONO_VLSB)
        self.init_display()

    def init_display(self):
        for cmd in (
            SET_DISP | 0x00,  # off
            # address setting
            SET_MEM_ADDR,
            0x00,  # horizontal
            # resolution and layout
            SET_DISP_START_LINE | 0x00,
            SET_SEG_REMAP | 0x01,  # column addr 127 mapped to SEG0
            SET_MUX_RATIO,
            self.height - 1,
            SET_COM_OUT_DIR | 0x08,  # scan from COM[N] to COM0
            SET_DISP_OFFSET,
            0x00,
            SET_COM_PIN_CFG,
            0x02 if self.width > 2 * self.height else 0x12,
            # timing and driving scheme
            SET_DISP_CLK_DIV,
            0x80,
            SET_PRECHARGE,
            0x22 if self.external_vcc else 0xF1,
            SET_VCOM_DESEL,
            0x30,  # 0.83*Vcc
            # display
            SET_CONTRAST,
            0xFF,  # maximum
            SET_ENTIRE_ON,  # output follows RAM contents
            SET_NORM_INV,  # not inverted
            # charge pump
            SET_CHARGE_PUMP,
            0x10 if self.external_vcc else 0x14,
            SET_DISP | 0x01,
        ):  # on
            self.write_cmd(cmd)
        self.fill(0)
        self.show()

    def poweroff(self):
        self.write_cmd(SET_DISP | 0x00)

    def poweron(self):
        self.write_cmd(SET_DISP | 0x01)

    def contrast(self, contrast):
        self.write_cmd(SET_CONTRAST)
        self.write_cmd(contrast)

    def invert(self, invert):
        self.write_cmd(SET_NORM_INV | (invert & 1))

    def show(self):
        x0 = 0
        x1 = self.width - 1
        if self.width == 64:
            # displays with width of 64 pixels are shifted by 32
            x0 += 32
            x1 += 32
        self.write_cmd(SET_COL_ADDR)
        self.write_cmd(x0)
        self.write_cmd(x1)
        self.write_cmd(SET_PAGE_ADDR)
        self.write_cmd(0)
        self.write_cmd(self.pages - 1)
        self.write_data(self.buffer)


class SSD1306_I2C(SSD1306):
    def __init__(self, width, height, i2c, addr=0x3C, external_vcc=False):
        self.i2c = i2c
        self.addr = addr
        self.temp = bytearray(2)
        self.write_list = [b"\x40", None]  # Co=0, D/C#=1
        super().__init__(width, height, external_vcc)

    def write_cmd(self, cmd):
        self.temp[0] = 0x80  # Co=1, D/C#=0
        self.temp[1] = cmd
        self.i2c.writeto(self.addr, self.temp)

    def write_data(self, buf):
        self.write_list[1] = buf
        self.i2c.writevto(self.addr, self.write_list)


class SSD1306_SPI(SSD1306):
    def __init__(self, width, height, spi, dc, res, cs, external_vcc=False):
        self.rate = 10 * 1024 * 1024
        dc.init(dc.OUT, value=0)
        res.init(res.OUT, value=0)
        cs.init(cs.OUT, value=1)
        self.spi = spi
        self.dc = dc
        self.res = res
        self.cs = cs
        import time

        self.res(1)
        time.sleep_ms(1)
        self.res(0)
        time.sleep_ms(10)
        self.res(1)
        super().__init__(width, height, external_vcc)

    def write_cmd(self, cmd):
        self.spi.init(baudrate=self.rate, polarity=0, phase=0)
        self.cs(1)
        self.dc(0)
        self.cs(0)
        self.spi.write(bytearray([cmd]))
        self.cs(1)

    def write_data(self, buf):
        self.spi.init(baudrate=self.rate, polarity=0, phase=0)
        self.cs(1)
        self.dc(1)
        self.cs(0)
        self.spi.write(buf)
        self.cs(1)
